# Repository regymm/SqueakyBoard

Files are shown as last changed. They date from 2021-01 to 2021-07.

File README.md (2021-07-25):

# SqueakyBoard

**A self-designed ZYNQ 7010 FPGA development board**

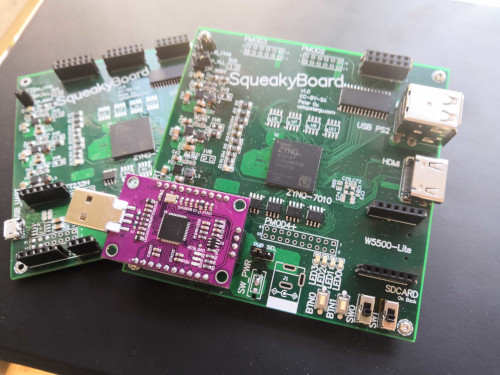
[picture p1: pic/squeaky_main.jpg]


#### Main Features

- 4-layer, 9.9 cm x 9.9 cm, meets JLCPCB requirements, friendly for hand-soldering, cost-optimized
- 28 K logic elements & Vivado and Xilinx SDK compatible, using the programmable logic of ZYNQ 7010 CLG400

#### Connectivity

- Pluggable CJMCU-FT232HL as JTAG downloader or USB-UART bridge
- Reserved standard 2x7 JTAG port
- SPI PSRAM up to 64 MBytes
- Basic HDMI
- ~~USB-to-UART~~
- Two USB ports, one connected directly and one via CH375b
- Micro SD Card
- Pluggable W5500-Lite module
- Up to 4 PMOD connector
- 4 LEDs, 2 slide switches, 2 push buttons
- Configuration via PS-side QSPI flash
- Power input via JTAG downloader, USB-to-UART, or 5V jack 

#### Testing

Untested parts: 

- 5V jack input
- SD card only SPI is tested
- PSRAM only the first(U4), up to QPI mode 62.5MHz -- this is because laziness
- USB direct connect only PS2 keyboard tested
- Use 7020 instead of 7010 -- is power supply sufficient?

Parts need remedy: 

- Slide switch need VCC connection removed to avoid short -- it's more bad switch than bad design
- USB(direct connection) needs pullup constraint because logic level problem(FPGA 3.3V vs PS2 5V), but it do work for some (extremely cheap) keyboards
- The crystal on front side connected to a pin with warning, so is not used

Failed parts: 

- USB to UART -- D- and D+ on the chip was accidentally inverted

#### Design Files

Sorry but I use Altium Designer. altium/ contains design files, altium_pdf/ contains readable schematic(with comment of failed parts) and layout. 

src/ contains example project source, bitstream, pre-generated SPI flash content, and xdc file. 

Be sure to follow the [noddr procedure](https://xilinx-wiki.atlassian.net/wiki/spaces/A/pages/18842377/Zynq-7000+AP+SoC+Boot+-+Booting+and+Running+Without+External+Memory+Tech+Tip) in Xilinx SDK

#### Warning

- Use as your own risk but feel free to ask me if any problem
- My testings are not sufficient
- No DDR or PS-side IO so the ARM cores are literally useless except booting from QSPI flash
- Using ingenuine JTAG downloader may have legal issue
- Electrostatic discharge should be taken care of -- it already has SMAJ5.0CA but who knows?
- Contains lead(Pb)
- It's a 4-layer so all common PCB design rules are put aside, signal integrity compromised 

#### Gallery

- Front view

  *with [ymmcu-ft2232](https://github.com/ustcpetergu/ymmcu-ft2232) and w5500-lite, thanks [USTCLUG](https://github.com/ustclug/) for the sticker*

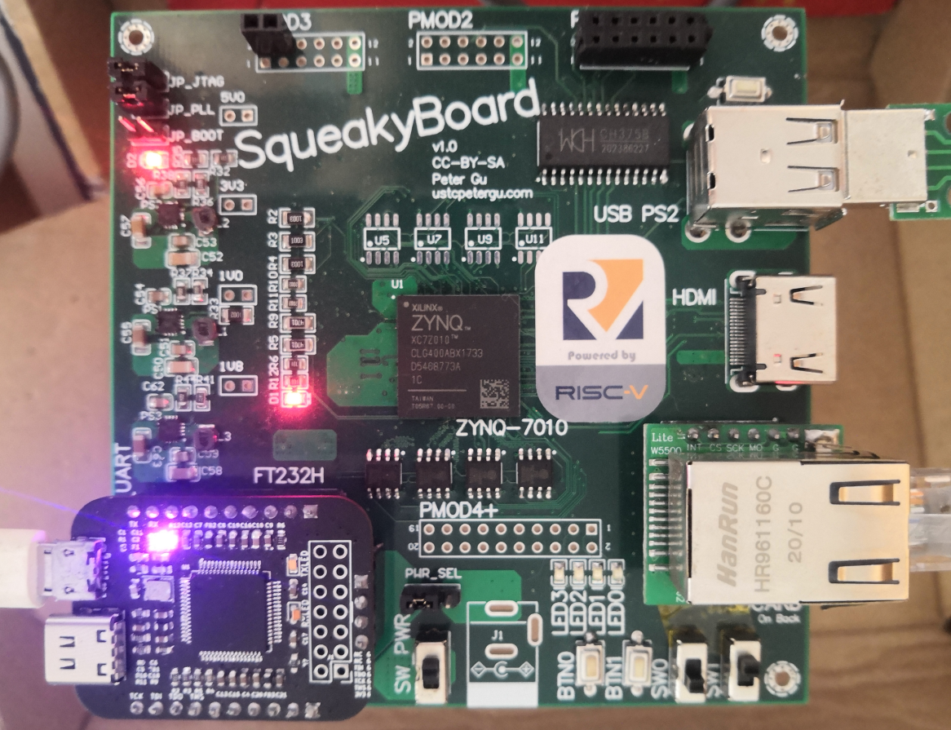
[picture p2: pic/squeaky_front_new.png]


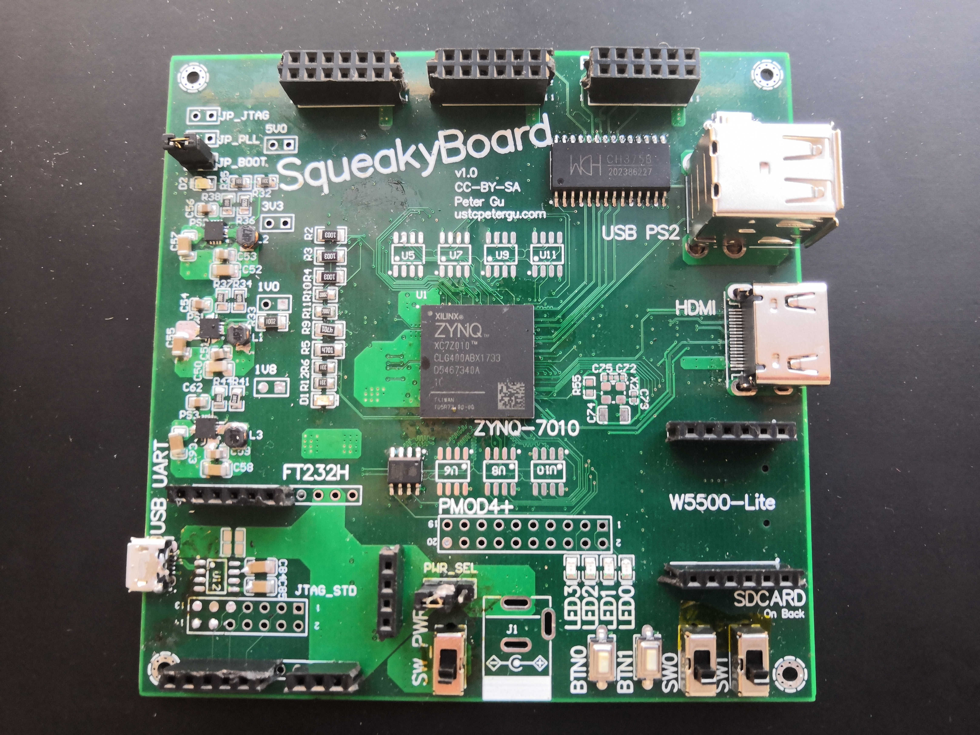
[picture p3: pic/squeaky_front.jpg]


- Back view

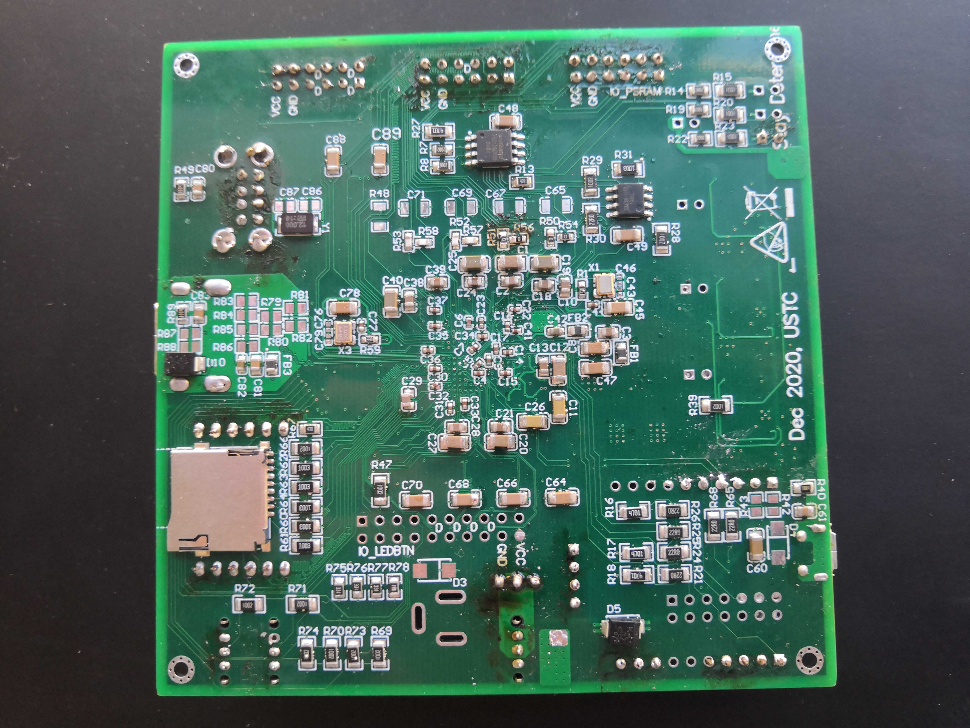
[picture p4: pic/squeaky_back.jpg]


- ILA showing some assembly loaded from SD card running on RISC-V core in PSRAM

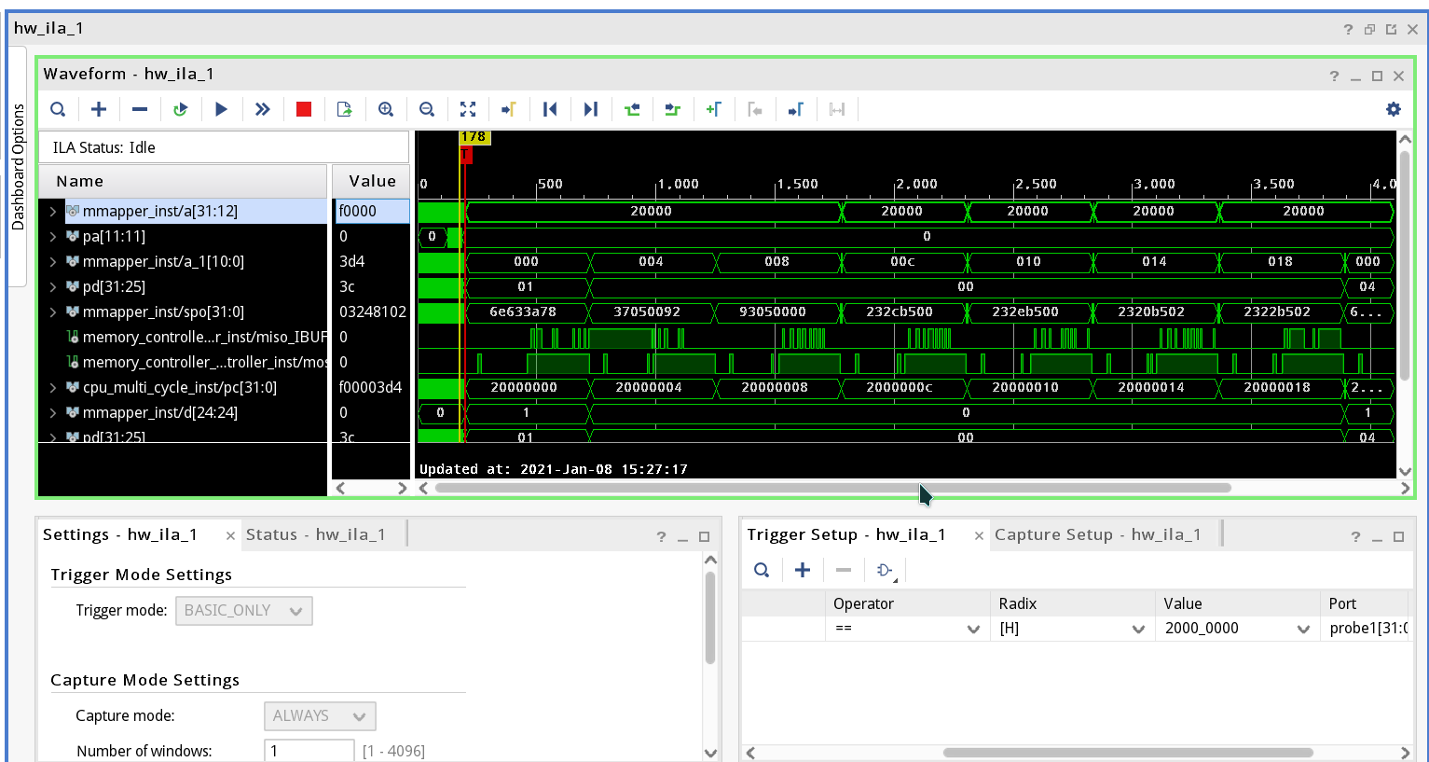
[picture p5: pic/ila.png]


#### Misc. 

**About the name**

https://nethackwiki.com/wiki/Trap#Squeaky_board

**Reference**

- Mainly UG933, some UG483 and UG585
- Testing files from Digilent and fpga4fun

**Cooperation**

I made one batch(5 pcs), 4 are soldered and 1 is left abandoned. Among the 4, 1 was sold, 1 was given to friend, and 2 are in my hands. If anyone want to make the board again using the PCB files, **please contact me**. I'll fix the UART bug, export Gerber if needed, and maybe mail you my excess components.

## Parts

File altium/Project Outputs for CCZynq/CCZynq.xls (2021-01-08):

Comment | Description | Designator | Footprint | LibRef | Quantity | My First Buy | Need All | Second buy need
Header 2 | Header, 2-Pin | 1V0, 1V8, 3V3, 5V0, JP_BOOT, JP_JTAG, JP_PLL | HDR1X2 | Header 2 | 7
PUSHBUTTON | SWITCH, PUSH BUTTON, TACTILE, SMD, SPST, 6X3.5X4.3mm | BTN0, BTN1, USBRST | SWPBS_SPST_6X3X5 | SWPBS_SPST_6X3X4 | 3
100uF | 贴片电容 | C1, C12, C19, C20, C25, C27, C40 | 1206_C | 1206 10uF (106) 10% 50V | 7 | 10 | 35 | 30
4.7uF | 贴片电容 | C2, C3, C10, C13, C18, C21, C24, C28, C29, C38, C39 | 0805_C | 0805 4.7uF (475) 10% 25V | 11 | 20 | 55 | 40
470nF | 贴片电容 | C4, C5, C6, C7, C9, C14, C15, C16, C17, C22, C23, C30, C31, C32, C33, C34, C35, C36, C37, C41, C44, C73, C77 | 0402_C | 0402 470nF (474) 10% 10V | 23 | 50 | 115 | 100
100nF | 贴片电容 | C8, C45, C47, C48, C49, C50, C52, C58, C64, C65, C66, C67, C68, C69, C70, C71, C74, C78, C84, C85, C88, C89 | 1206_C | 1206 100nF (104) 10% 50V | 22 | 50 | 110 | 50
47uF | 贴片电容 | C11, C26 | 1206_C | 1206 10uF (106) 10% 50V | 2 | 5 | 10 | 10
10uF | 贴片电容 | C42, C82 | 0603_C | 0603 10uF (106) 10% 10V | 2 | 10 | 10
NC | 贴片电容 | C43, C46, C72, C75, C76, C79 | 0402_C | 0402 470nF (474) 10% 10V | 6 | NC | NC
22uF | 贴片电容 | C51, C53, C59 | 0805_C | 0805 22uF (226) 20% 25V | 3 | 20 | 15
3.3nF | 贴片电容 | C54, C56, C62 | 0805_C | 0805 3.3nF (332) 10% 50V | 3 | 50 | 15
10uF | 贴片电容 | C55, C57, C60, C63 | 1206_C | 1206 10uF (106) 10% 50V | 4 | 10 | 20 | 10
1nF | 贴片电容 | C61, C80, C81, C83 | 0805_C | 0805 1nF (102) 10% 50V | 4 | 50 | 20
20pF | 贴片电容 | C86, C87 | 0805_C | 0805 20pF (200) 5% 50V | 2 | 0 | 10 | 50
Green | 发光二极管 | D1, D2, LED0, LED1, LED2, LED3 | 0805_LED_S1 | 0805 翠绿 | 6
SMAJ5.0CA | 二极管 TVS | D3, D4, D5 | SMA(DO-214AC)_S1 | SMA(DO-214AC) SS210 | 3
NC | 二极管 TVS | D10 | SMA(DO-214AC)_S1 | SMA(DO-214AC) SS210 | 1
120Ω@100MHz | 贴片磁珠 | FB1, FB2, FB3 | 0805_L | 0805 600Ω 25% 100MHz | 3
HDMI_A | CONN, HDMI, Receptacle, TYPE A, 19P, RIGH-ANGLE | HDMI | HDMI_A | CONN_HDMI_A | 1
DC_POWER_JACK | CONN, PWR JACK DC, PLUG DIAM 2.0MM RA THD | J1 | JAC_PWR2MM | CONN_PWR_JACK2MM | 1
SDCARD | SD MICRO exist in Iran, Attend 112J-TDAR-R01 | J2 | SDMICRO_AT | SOCKET_SDMICRO_AT | 1
HDRF6 | CONN, HEADER, Female, pitch: 2.54mm, 6POS | J3, J4 | HDR_F_1X6 | HDR_F_1X6 | 2
=VALUE | Header, 10-Pin | J_FT_AC, J_FT_AD | HDR1X10 | Header 10 | 2
=VALUE | Header, 4-Pin | J_FT_PWR | HDR1X4 | Header 4 | 1
JTAG Header | Header, 7-Pin, Dual row | JTAG_STD | HDR2X7 | Header 7X2 | 1
252012CDMCDS2R2MC | Inductor | L1, L2, L3 | INDPM2520X120N | 252012CDMCDS2R2MC | 3
Header 6X2 | Header, 6-Pin, Dual row | PMOD1, PMOD2, PMOD3 | HDR2X6 | Header 6X2 | 3
Header 10X2 | Header, 10-Pin, Dual row | PMOD4+ | HDR2X10 | Header 10X2 | 1
TLV62130RGTR | Power Supply | PS1, PS2, PS3 | QFN50P300X300X100-17N-D | TLV62130RGTR | 3
PWR SEL | Header, 3-Pin | PWR_SEL | HDR1X3 | Header 3 | 1
33Ω | 贴片电阻 | R1, R55, R59 | 0603_R | 0603 33Ω (33R0) 1% | 3 | 100 | 15
100KΩ | 贴片电阻 | R2, R3, R4, R31, R60, R61, R62, R63, R64 | 1206_R | 1206 100KΩ (1003) 1% | 9 | 50 | 45
4.7KΩ | 贴片电阻 | R5, R9, R16, R17, R18, R27 | 1206_R | 1206 4.7KΩ (4701) 1% | 6 | 50 | 30
330Ω | 贴片电阻 | R6, R12, R32, R35, R75, R76, R77, R78 | 0805_R | 0805 330Ω (3300) 1% | 8 | 100 | 40
20KΩ | 贴片电阻 | R7, R8, R10, R11, R14, R19, R22, R37 | 0805_R | 0805 20KΩ (2002) 1% | 8 | 100 | 40
47Ω | 贴片电阻 | R13, R67, R79, R80, R81, R82, R83, R84, R85, R86 | 0805_R | 0805 47Ω (47R0) 1% | 10 | 50 | 50 | no
1KΩ | 贴片电阻 | R15, R20, R23 | 1206_R | 1206 1KΩ (1001) 1% | 3 | 50 | 15
22Ω | 贴片电阻 | R21, R24, R25, R26, R30, R65, R68 | 1206_R | 1206 22Ω (22R0) 1% | 7 | 50 | 35
10KΩ | 贴片电阻 | R28, R29, R33, R39, R47, R48, R66, R69, R70, R71, R72, R73, R74 | 1206_R | 1206 10KΩ (1002) 1% | 13 | 50 | 65 | y
4.99KΩ | 贴片电阻 | R34 | 0805_R | 0805 4.99KΩ (4991) 1% | 1
56.2KΩ | 贴片电阻 56.2k | R36 | 0805_R | 0805 56KΩ (5602) 1% | 1
18KΩ | 贴片电阻 | R38 | 0805_R | 0805 18KΩ (1802) 1% | 1
1MΩ | 贴片电阻 | R40, R49, R89 | 0805_R | 0805 1MΩ (1004) 1% | 3
18.7KΩ | 贴片电阻 18.7k | R41 | 0805_R | 0805 18KΩ (1802) 1% | 1
0Ω NC | 贴片电阻 | R42, R43, R45, R46 | 0805_R | 0805 0Ω (0R0) 1% | 4
15KΩ | 贴片电阻 | R44 | 0805_R | 0805 15KΩ (1502) 1% | 1
0Ω NC | 贴片电阻 | R50, R51, R52, R53, R54, R56, R57, R58 | 0603_R | 0603 0Ω (0R0) 1% | 8 | 100
NC | 贴片电阻 | R87, R88 | 0805_R | 0805 1MΩ (1004) 1% | 2
SlideSwitch | SWITCH, SLIDE, SPDT, 8.6X4.3mm, THD | SW0, SW1, SW_PWR | SWSLIDT_SPDT_S_8X4 | SWSLIDT_SPDT_S_8X4 | 3
XC7Z010-1CLG400I | 667 MHz Zynq?7000 AP SoC, 130 PS I/O, 100 FPGA I/O, 400-Ball BGA, Speed Grade 1, Industrial Grade, Pb-Free | U1 | CLG400 | XC7Z010-1CLG400I | 1
W25Q128JVSIQTR | Flash ROM | U2 | SOIC-8_208mil | W25Q128JVSIQTR_[C97521] | 1
SGM706-SYS8 | MCU Supervisor, 150mil SOP-8 | U3 | SOIC-8_150mil | EEPROM/AT24C256C-SSHL-T_[C6482] | 1
ESP-PSRAM-64H | PSRAM, 150mil SOP-8 | U4, U5, U6, U7, U8, U9, U10, U11 | SOIC-8_150mil | EEPROM/AT24C256C-SSHL-T_[C6482] | 8
CH330N | PSRAM, 150mil SOP-8 | U12 | SOIC-8_150mil | EEPROM/AT24C256C-SSHL-T_[C6482] | 1
CH375B | USB | U13 | SOIC-28_300mil | CH376S_[C14166] | 1
USB A 2.0 x2 | Connector | USB PS2 | 0672983090 | 0672983090 | 1
CONN_USB_MICROB | CONN, USB, MICRO B, R/A, SMD, BOTTOM MOUNT, SHT | USB_UART | USB_MICRO_B_BM_SHT1 | CONN_USB_MICRO_B_BM_SHT1 | 1
40MHz | CRYSTAL 40.00 MHZ 4pF, 10PPM | X1, X2 | XTL_4_3225 | XTL_4_40MHz_3225A | 2
NC | CRYSTAL 40.00 MHZ 4pF, 10PPM | X3 | XTL_4_3225 | XTL_4_40MHz_3225A | 1
12MHz | 贴片晶振 | Y1 | SMD-5032_2P | SMD-5032_2P 11.0592MHZ 20PF 20PPM | 1

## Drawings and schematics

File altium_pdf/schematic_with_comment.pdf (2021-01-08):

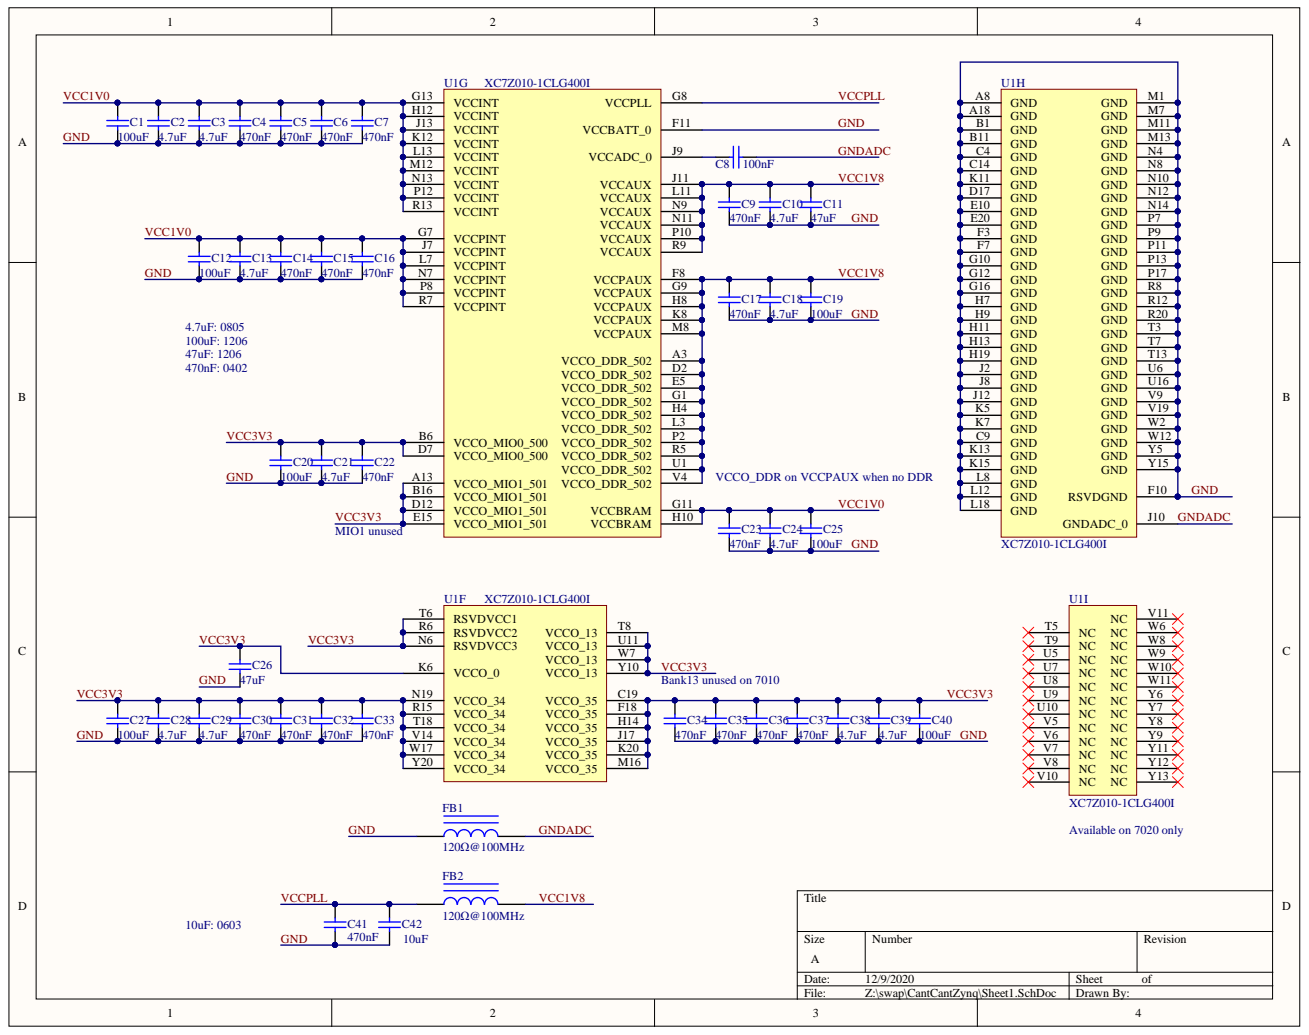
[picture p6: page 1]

VCCO_DDR on VCCPAUX when no DDR

VCC3V3 | RSVDVCC2 R6

C26 | VCCO_0 K6

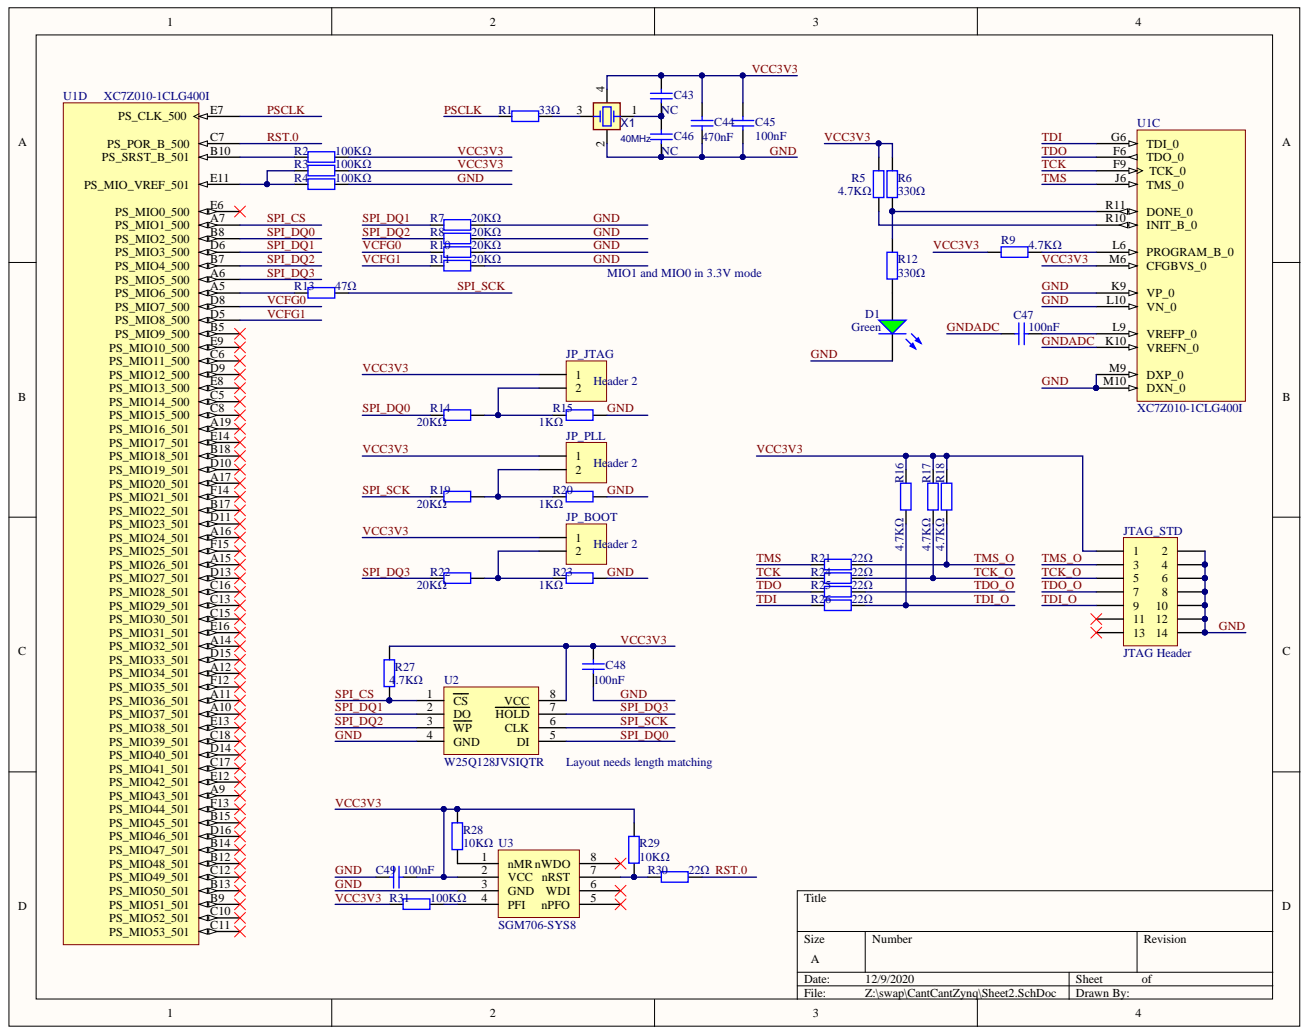
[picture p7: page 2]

TDO_O
TDI_O

Layout needs length matching

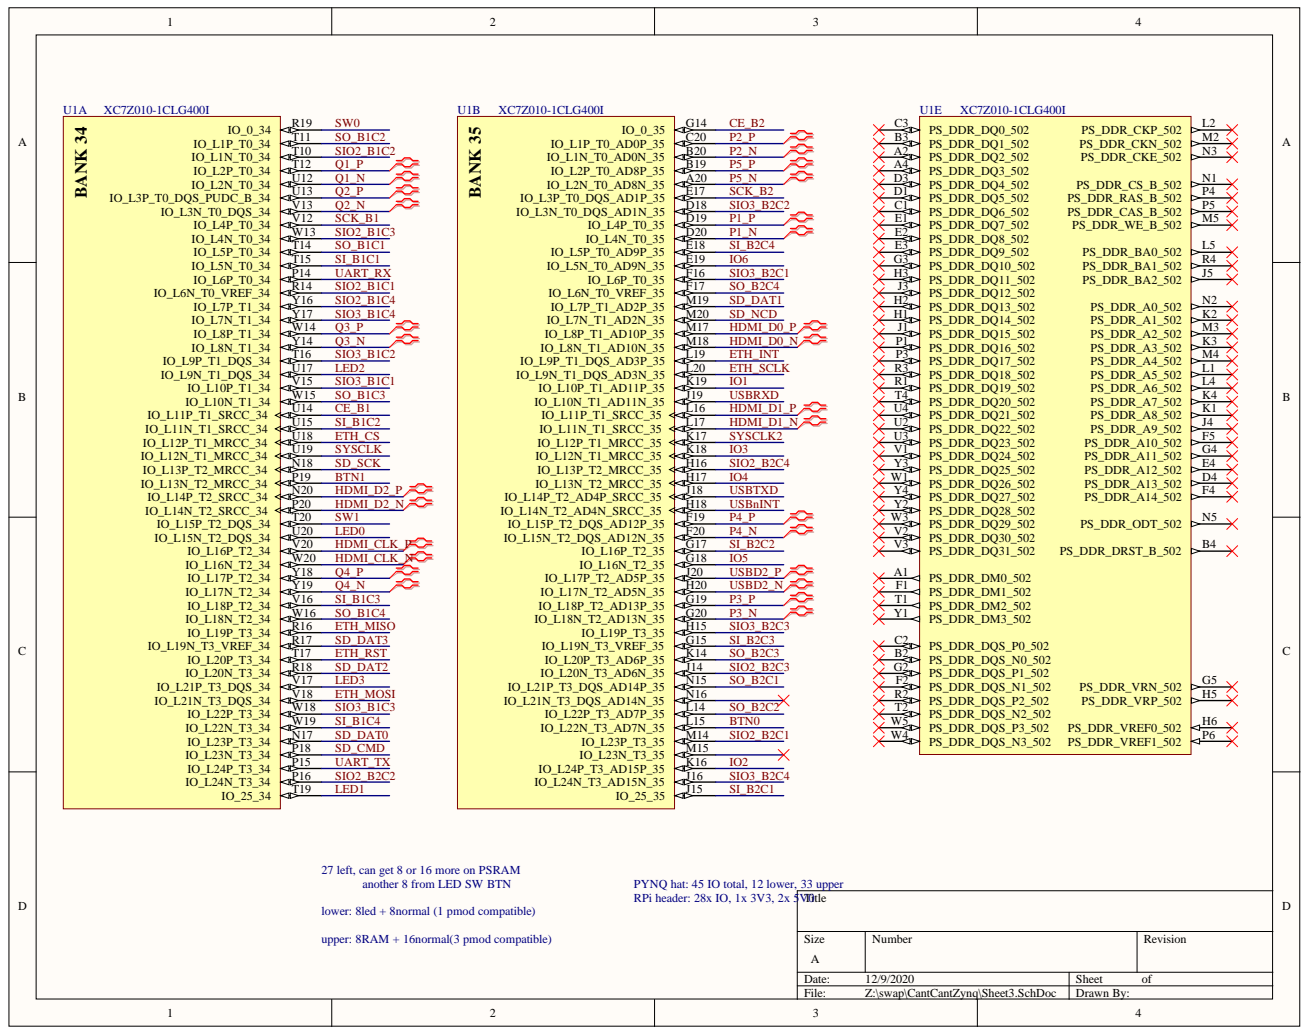
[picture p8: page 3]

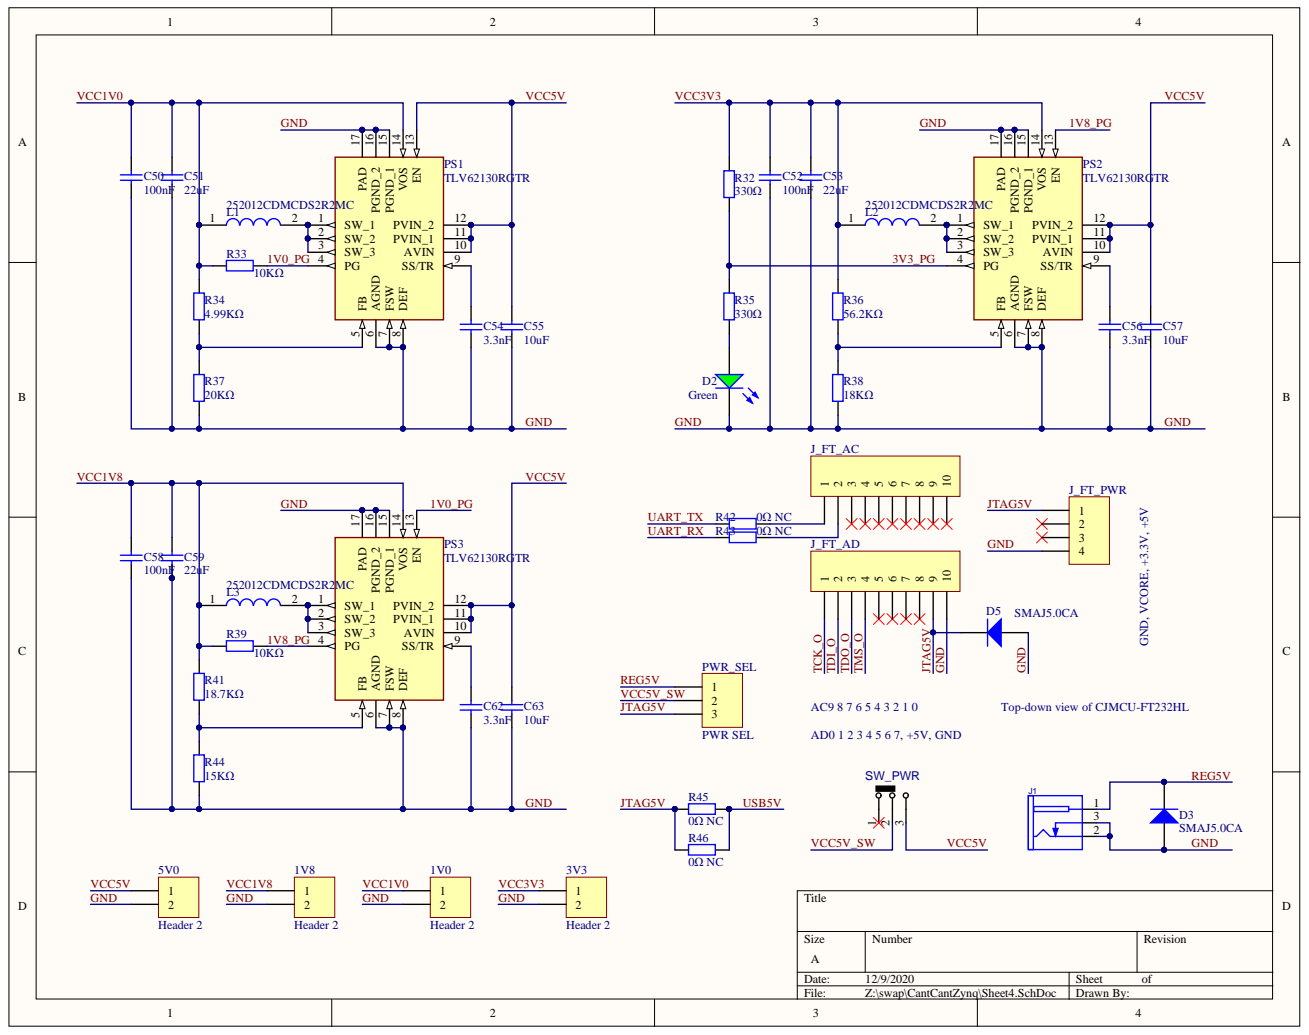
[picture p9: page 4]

Top-down view of CJMCU-FT232HL

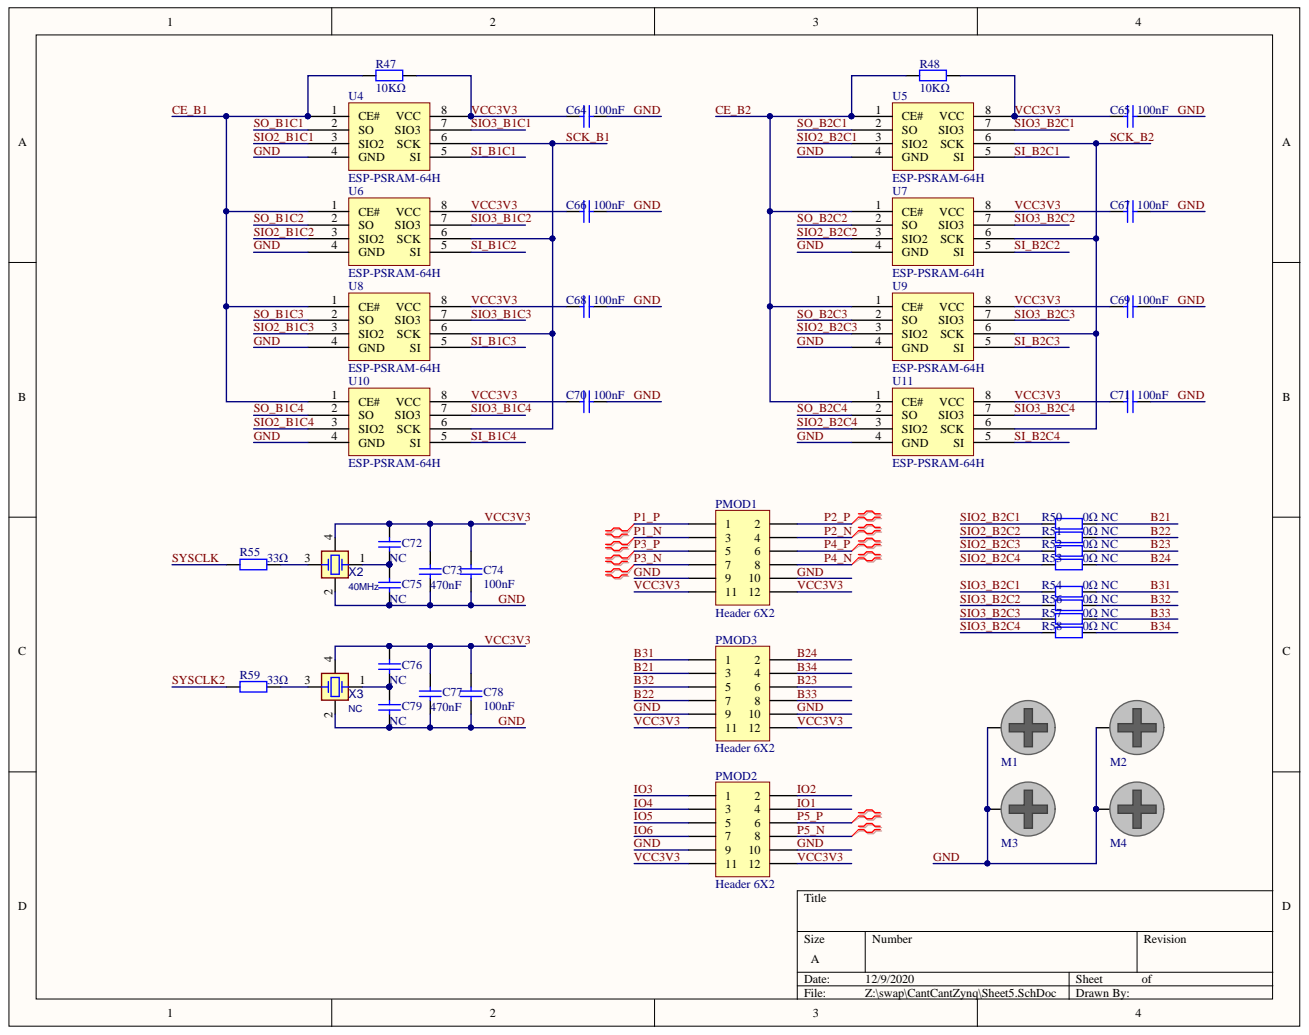
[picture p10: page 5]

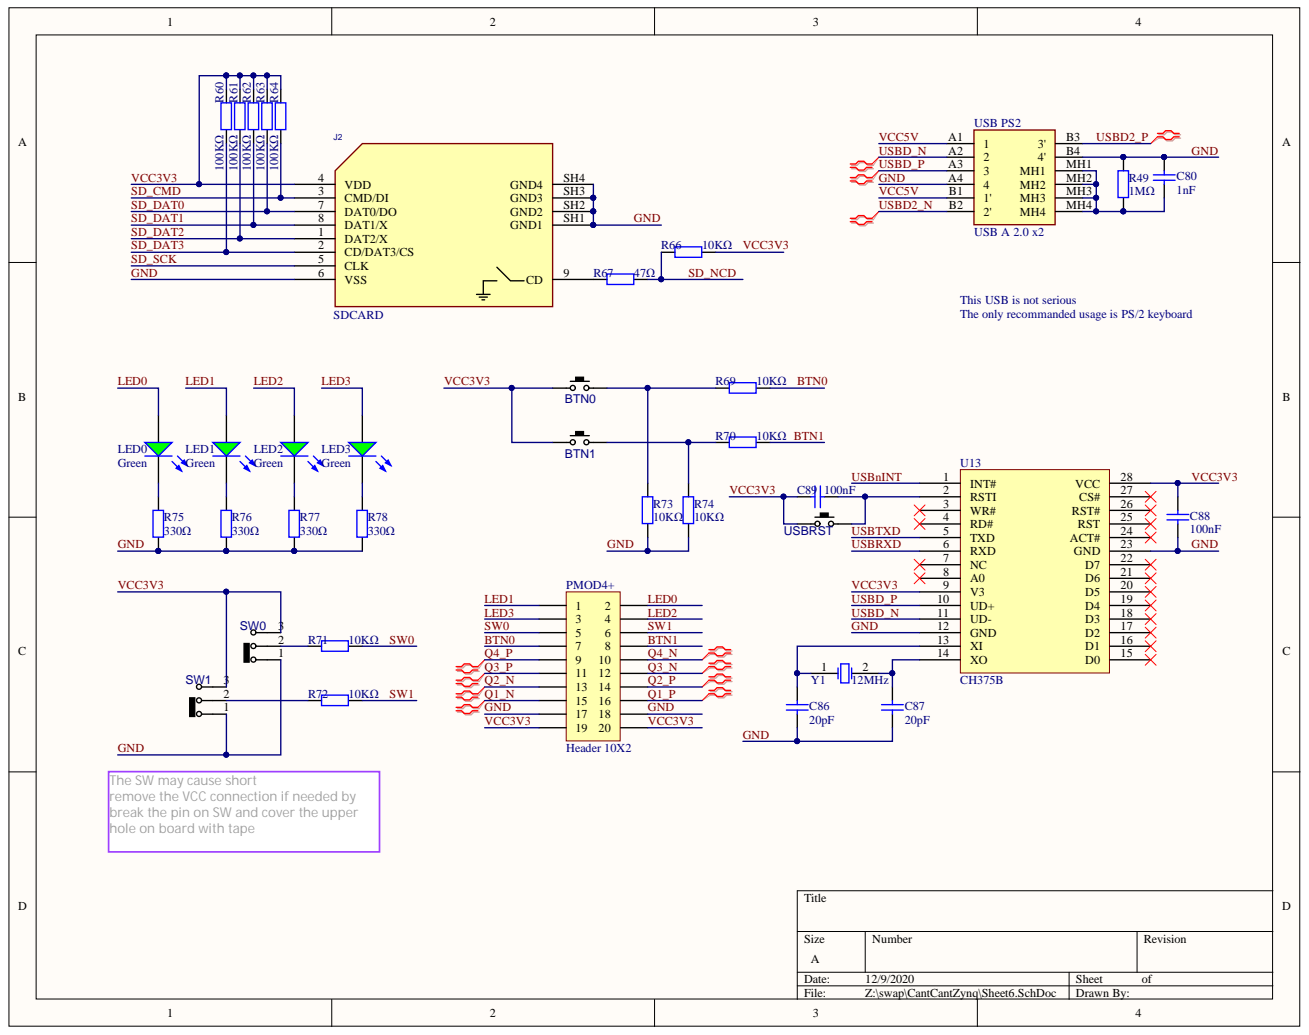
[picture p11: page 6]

This USB is not serious
The only recommanded usage is PS/2 keyboard

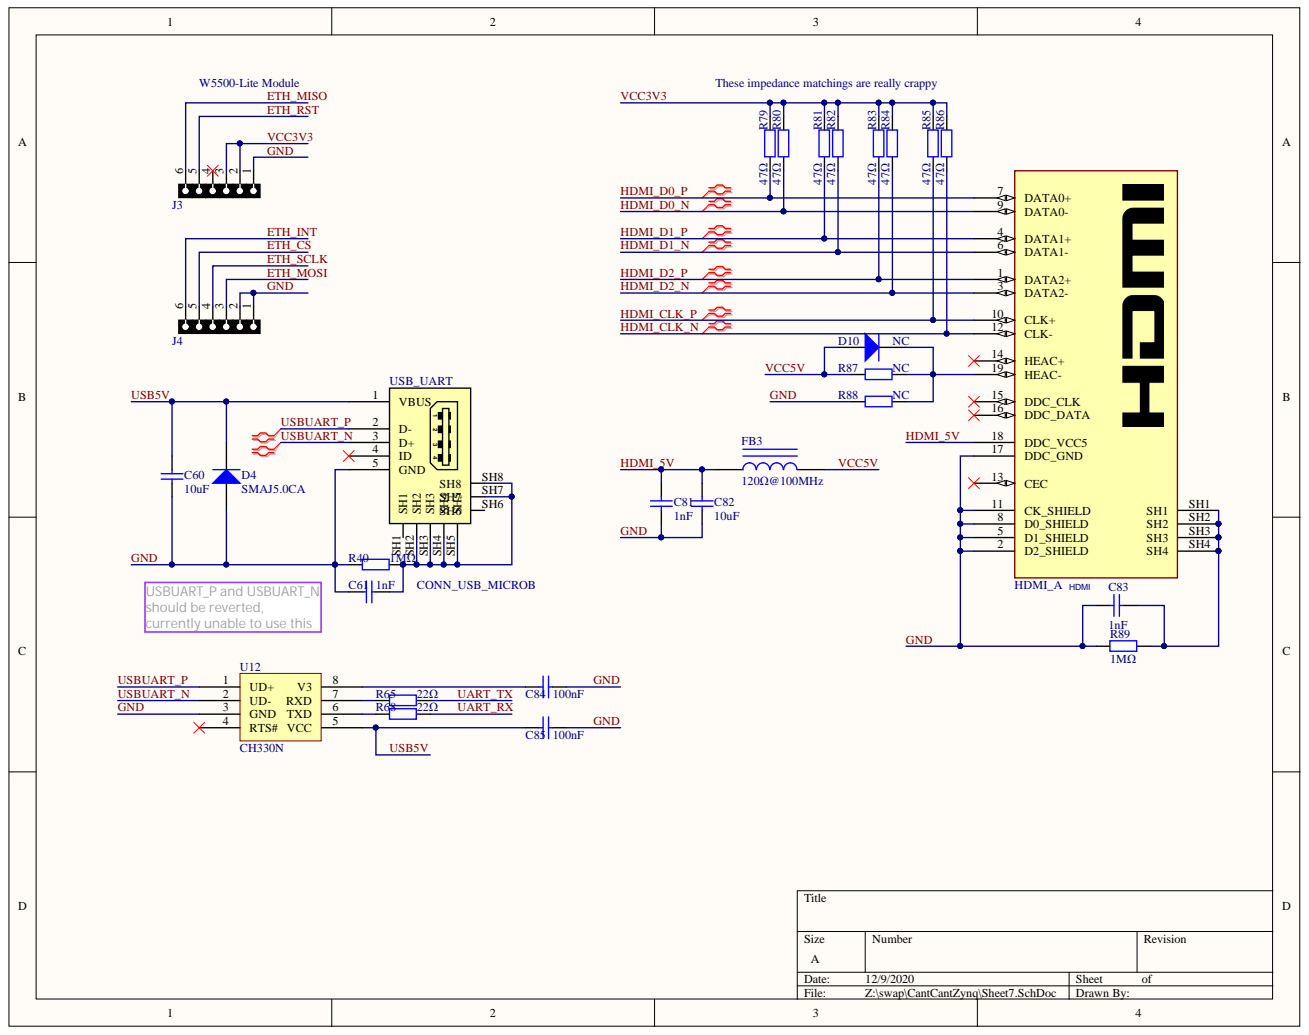
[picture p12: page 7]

These impedance matchings are really crappy

HDMI_D0_N

HDMI_D1_P | DATA1+ 4

HEAC- 19 HEAC+ 14

DDC_CLK 15

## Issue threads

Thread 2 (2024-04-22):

W5500

dookei, 2024-04-22:
Hi did you test the W5500 speed ? How much can you get out of it ?

regymm, 2024-04-23:
Hi, I only wrote an SPI driver for it and assigned it an IP address, without testing the speed. Since it's a 100M/10M chip, I guess in principle it can go to 100M if the SPI clock speed can be raised. The maximum SPI clock is 80M, which seems not that easy to run at.

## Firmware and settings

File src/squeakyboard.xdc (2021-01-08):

## .xdc file for SqueakyBoard by petergu

## sysclk
#set_property -dict {PACKAGE_PIN K17 IOSTANDARD LVCMOS33} [get_ports sysclk]
#create_clock -period 20.000 -name clk_50M -waveform {0.000 10.000} -add [get_ports sysclk]

## buttons, switches and LEDs
#set_property -dict {PACKAGE_PIN L15 IOSTANDARD LVCMOS33} [get_ports {btn[0]}]
#set_property -dict {PACKAGE_PIN P19 IOSTANDARD LVCMOS33} [get_ports {btn[1]}]
#set_property -dict {PACKAGE_PIN R19 IOSTANDARD LVCMOS33} [get_ports {sw[0]}]
#set_property -dict {PACKAGE_PIN T20 IOSTANDARD LVCMOS33} [get_ports {sw[1]}]
#set_property -dict {PACKAGE_PIN U20 IOSTANDARD LVCMOS33} [get_ports {led[0]}]
#set_property -dict {PACKAGE_PIN T19 IOSTANDARD LVCMOS33} [get_ports {led[1]}]
#set_property -dict {PACKAGE_PIN U17 IOSTANDARD LVCMOS33} [get_ports {led[2]}]
#set_property -dict {PACKAGE_PIN V17 IOSTANDARD LVCMOS33} [get_ports {led[3]}]


## PMOD1
#set_property -dict {PACKAGE_PIN D19 IOSTANDARD LVCMOS33} [get_ports p1p]
#set_property -dict {PACKAGE_PIN D20 IOSTANDARD LVCMOS33} [get_ports p1n]
#set_property -dict {PACKAGE_PIN C20 IOSTANDARD LVCMOS33} [get_ports p2p]
#set_property -dict {PACKAGE_PIN B20 IOSTANDARD LVCMOS33} [get_ports p2n]
#set_property -dict {PACKAGE_PIN G19 IOSTANDARD LVCMOS33} [get_ports p3p]
#set_property -dict {PACKAGE_PIN G20 IOSTANDARD LVCMOS33} [get_ports p3n]
#set_property -dict {PACKAGE_PIN F19 IOSTANDARD LVCMOS33} [get_ports p4p]
#set_property -dict {PACKAGE_PIN F20 IOSTANDARD LVCMOS33} [get_ports p4n]

## PMOD2
#set_property -dict {PACKAGE_PIN B19 IOSTANDARD LVCMOS33} [get_ports p5p]
#set_property -dict {PACKAGE_PIN A20 IOSTANDARD LVCMOS33} [get_ports p5n]
#set_property -dict {PACKAGE_PIN K19 IOSTANDARD LVCMOS33} [get_ports io1]
#set_property -dict {PACKAGE_PIN K16 IOSTANDARD LVCMOS33} [get_ports io2]
#set_property -dict {PACKAGE_PIN K18 IOSTANDARD LVCMOS33} [get_ports io3]
#set_property -dict {PACKAGE_PIN H17 IOSTANDARD LVCMOS33} [get_ports io4]
#set_property -dict {PACKAGE_PIN G18 IOSTANDARD LVCMOS33} [get_ports io5]
#set_property -dict {PACKAGE_PIN E19 IOSTANDARD LVCMOS33} [get_ports io6]

## PMOD4+
#set_property -dict {PACKAGE_PIN T12 IOSTANDARD LVCMOS33} [get_ports q1p]
#set_property -dict {PACKAGE_PIN U12 IOSTANDARD LVCMOS33} [get_ports q1n]
#set_property -dict {PACKAGE_PIN U13 IOSTANDARD LVCMOS33} [get_ports q2p]
#set_property -dict {PACKAGE_PIN V13 IOSTANDARD LVCMOS33} [get_ports q2n]
#set_property -dict {PACKAGE_PIN W14 IOSTANDARD LVCMOS33} [get_ports q3p]
#set_property -dict {PACKAGE_PIN Y14 IOSTANDARD LVCMOS33} [get_ports q3n]
#set_property -dict {PACKAGE_PIN Y18 IOSTANDARD LVCMOS33} [get_ports q4p]
#set_property -dict {PACKAGE_PIN Y19 IOSTANDARD LVCMOS33} [get_ports q4n]

# W5500-Lite
#set_property -dict {PACKAGE_PIN U18 IOSTANDARD LVCMOS33} [get_ports eth_cs]
#set_property -dict {PACKAGE_PIN L20 IOSTANDARD LVCMOS33} [get_ports eth_sclk]
#set_property -dict {PACKAGE_PIN V18 IOSTANDARD LVCMOS33} [get_ports eth_mosi]
#set_property -dict {PACKAGE_PIN R16 IOSTANDARD LVCMOS33} [get_ports eth_miso]
#set_property -dict {PACKAGE_PIN T17 IOSTANDARD LVCMOS33} [get_ports eth_rst]
#set_property -dict {PACKAGE_PIN L19 IOSTANDARD LVCMOS33} [get_ports eth_int]

# HDMI
#set_property -dict {PACKAGE_PIN W20 IOSTANDARD TMDS_33} [get_ports TMDSn_clock]
#set_property -dict {PACKAGE_PIN V20 IOSTANDARD TMDS_33} [get_ports TMDSp_clock]
#set_property -dict {PACKAGE_PIN M18 IOSTANDARD TMDS_33} [get_ports {TMDSn[0]}]
#set_property -dict {PACKAGE_PIN M17 IOSTANDARD TMDS_33} [get_ports {TMDSp[0]}]
#set_property -dict {PACKAGE_PIN L17 IOSTANDARD TMDS_33} [get_ports {TMDSn[1]}]
#set_property -dict {PACKAGE_PIN L16 IOSTANDARD TMDS_33} [get_ports {TMDSp[1]}]
#set_property -dict {PACKAGE_PIN P20 IOSTANDARD TMDS_33} [get_ports {TMDSn[2]}]
#set_property -dict {PACKAGE_PIN N20 IOSTANDARD TMDS_33} [get_ports {TMDSp[2]}]

# UART FAILED
#set_property -dict {PACKAGE_PIN P15 IOSTANDARD LVCMOS33} [get_ports uart_tx]
#set_property -dict {PACKAGE_PIN P14 IOSTANDARD LVCMOS33} [get_ports uart_rx]

# USB PS2
#set_property -dict {PACKAGE_PIN J20 IOSTANDARD LVCMOS33} [get_ports usbdp]
#set_property -dict {PACKAGE_PIN H20 IOSTANDARD LVCMOS33} [get_ports usbdn]
#set_property PULLUP TRUE [get_ports usbdp]
#set_property PULLUP TRUE [get_ports usbdn]

# SD Card
#set_property -dict {PACKAGE_PIN M20 IOSTANDARD LVCMOS33} [get_ports sd_ncd]
#set_property -dict {PACKAGE_PIN N17 IOSTANDARD LVCMOS33} [get_ports sd_dat0]
#set_property -dict {PACKAGE_PIN M19 IOSTANDARD LVCMOS33} [get_ports sd_dat1]
#set_property -dict {PACKAGE_PIN R18 IOSTANDARD LVCMOS33} [get_ports sd_dat2]
#set_property -dict {PACKAGE_PIN R17 IOSTANDARD LVCMOS33} [get_ports sd_dat3]
#set_property -dict {PACKAGE_PIN P18 IOSTANDARD LVCMOS33} [get_ports sd_cmd]
#set_property -dict {PACKAGE_PIN N18 IOSTANDARD LVCMOS33} [get_ports sd_sck]
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

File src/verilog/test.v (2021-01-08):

`timescale 1ns / 1ps

module test
	(
		input sysclk, 

		input [1:0]sw,
		input [1:0]btn,
		output wire [3:0]led,

		output reg p1p = 1,
		output reg p1n = 1,
		output reg p2p = 1,
		output reg p2n = 1,
		output reg p3p = 1,
		output reg p3n = 1,
		output reg p4p = 1,
		output reg p4n = 1,

		output reg q1p = 1,
		output reg q1n = 1,
		output reg q2p = 1,
		output reg q2n = 1,
		output reg q3p = 1,
		output reg q3n = 1,
		output reg q4p = 1,
		output reg q4n = 1,

		output reg p5p = 1,
		output reg p5n = 1,
		output reg io1 = 1,
		output reg io2 = 1,
		output reg io3 = 1,
		output reg io4 = 1,
		output reg io5 = 1,
		output reg io6 = 1,

		output [2:0]TMDSp, TMDSn,
		output TMDSp_clock, TMDSn_clock,

		(* mark_debug = "true" *) input usbdp,
		(* mark_debug = "true" *) input usbdn,

		output uart_tx,
		input uart_rx
		//input eth_cs
	);

	wire clk_pix;
	wire clk_tmds;
	clk_wiz_1 clk_wiz_0_inst(
		.sysclk(sysclk),
		.reset(btn[1]),
		.clk_pix(clk_pix),
		.clk_tmds(clk_tmds)
	);

	hdmi_demo hdmi_demo_inst
	(
		.clk_pix(clk_pix),
		.clk_tmds(clk_tmds),
		.TMDSp(TMDSp),
		.TMDSn(TMDSn),
		.TMDSp_clock(TMDSp_clock),
		.TMDSn_clock(TMDSn_clock)
	);

	assign uart_tx = uart_rx;

	(* mark_debug = "true" *) wire [31:0]keycodeout;
	ps2_demo ps2_demo_inst
	(
		.clk(sysclk),
		.kclk(usbdp),
		.kdata(usbdn),
		.keycodeout(keycodeout)
	);


	//reg [23:0]counter = 0;
	//always @ (posedge eth_cs) begin // 10MHz
		//if (btn[0]) counter <= 0;
		//else counter <= counter + 1;
	//end

	//reg [23:0]counter2 = 0;
	//always @ (posedge clk_out1) begin // 5MHz
		//counter2 <= counter2 + 1;
	//end
	//reg [23:0]counter3 = 0;
	//always @ (posedge clk_out2) begin // 20MHz
		//counter3 <= counter3 + 1;
	//end
	//reg [23:0]counter4 = 0;
	//always @ (posedge clk_out3) begin // 125MHz
		//counter4 <= counter4 + 1;
	//end
	//assign led[3:1] = counter[23:21];
	
	//assign led[0] = counter[22];
	//assign led[1] = counter2[22];
	//assign led[2] = counter3[22];
	//assign led[3] = counter4[22];
	
	assign led[3:0] = {btn[0], ~btn[1], sw[0], ~sw[1]};
	
	//assign led[0] = btn[0];
	//assign led[1] = ~btn[1];
	//assign led[2] = 1'b1;
	//assign led[3] = ~sw[1] & ~sw[0];
endmodule

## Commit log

2020-10-18 Initial commit, working on sch
    [CCZynq.PcbDoc, CCZynq.PrjPCB, Sheet1.SchDoc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]
2020-10-24 Working on it
    [CCZynq.PcbDoc, CCZynq.PrjPCB, Sheet1.SchDoc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]
2020-10-24 Added decouping caps
    [CCZynq.PcbDoc, Sheet1.SchDoc, Sheet2.SchDoc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]
2020-10-26 Decide to use CJMCU FT232HL instead of on-board JTAG
    [Sheet1.SchDoc, Sheet2.SchDoc, Sheet4.SchDoc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]
2020-10-27 Updated peripherals and some placement
    [CCZynq.PrjPCB, Sheet1.SchDoc, Sheet2.SchDoc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]
2020-10-28 continue on fpga wiring
    [Sheet1.SchDoc, Sheet2.SchDoc, Sheet3.SchDoc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]
2020-10-30 Places caps, added HDMI
    [Sheet2.SchDoc, Sheet3.SchDoc, Sheet4.SchDoc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]
2020-10-31 Continue on update, considering Ethernet
    [Sheet3.SchDoc, Sheet4.SchDoc, Sheet6.SchDoc]
2020-11-03 Continue on GPIO design
    [Backup.SchDoc, Sheet1.SchDoc, Sheet2.SchDoc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]
2020-11-05 Push because dev paused a few days
    [Sheet2.SchDoc, Sheet3.SchDoc, Sheet4.SchDoc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]
2020-11-11 Continue updateing...
    [CCZynq.PrjPCB, Sheet2.SchDoc, Sheet3.SchDoc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]
2020-11-14 Begin on layout and modifications
    [Backup.SchDoc, Sheet1.SchDoc, Sheet2.SchDoc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]
2020-11-19 Update, begin diff pair routing
    [Sheet1.SchDoc, Sheet2.SchDoc, Sheet3.SchDoc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]
2020-11-29 Configuring pin and memory
    [Sheet3.SchDoc, Sheet6.SchDoc, Sheet7.SchDoc]
2020-11-29 Continue routing
    [Sheet3.SchDoc, Sheet5.SchDoc, Sheet6.SchDoc]
2020-12-02 first version routing finished
    [Sheet2.SchDoc, Sheet3.SchDoc, Sheet4.SchDoc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]
2020-12-07 Seems ready for production
    [CCZynq.PrjPCB, Sheet2.SchDoc, Sheet3.SchDoc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]
2020-12-09 Ready for production
    [Sheet1.SchDoc, Sheet2.SchDoc]
2021-01-08 Ready to publish
    [Backup.SchDoc, CCZynq.PrjPCB, CCZynq.xls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]
